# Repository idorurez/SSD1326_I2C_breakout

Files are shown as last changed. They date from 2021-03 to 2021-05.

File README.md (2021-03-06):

# SSD1326 256x32 I2C oled breakout

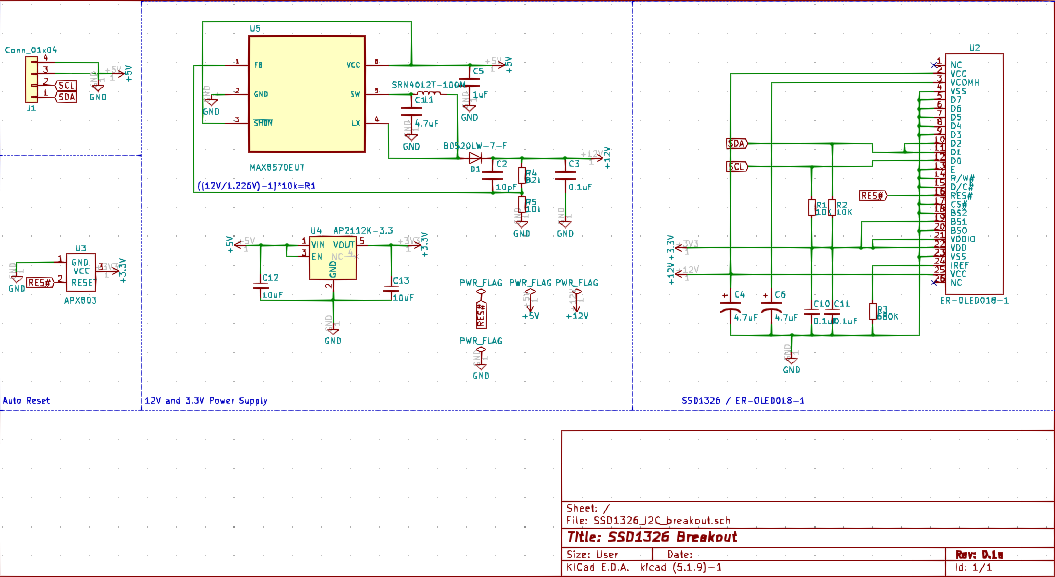
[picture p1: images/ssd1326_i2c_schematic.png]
schematic

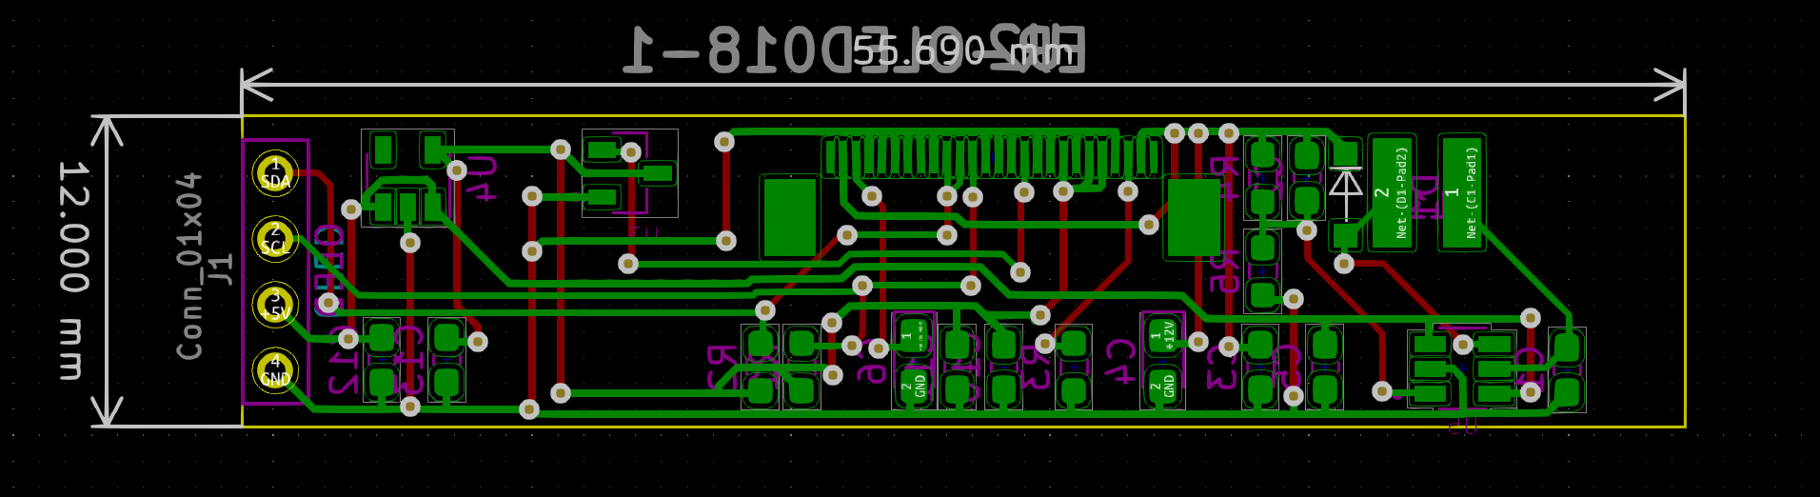
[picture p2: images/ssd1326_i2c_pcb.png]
pcb


## Features
* 5V+ in
* I2C
* Voltage regulator V3.3 out for logic
* Step up to 12V+ to power oled panel
* For use with ER-OLED01B-1 w/26 pin Ziff connector

## Notes
* `datasheet` folder includes datasheets for everything used here as well as ones I abandoned
* `onigaku` repo (not included in this repo) has all symbols and footprints are available

## Inspiration
* Adafruit schematics for latest SSD1306 breakout boards
* https://hackaday.io/project/173753-oled-breakout-board-with-dc-dc-step-up/details

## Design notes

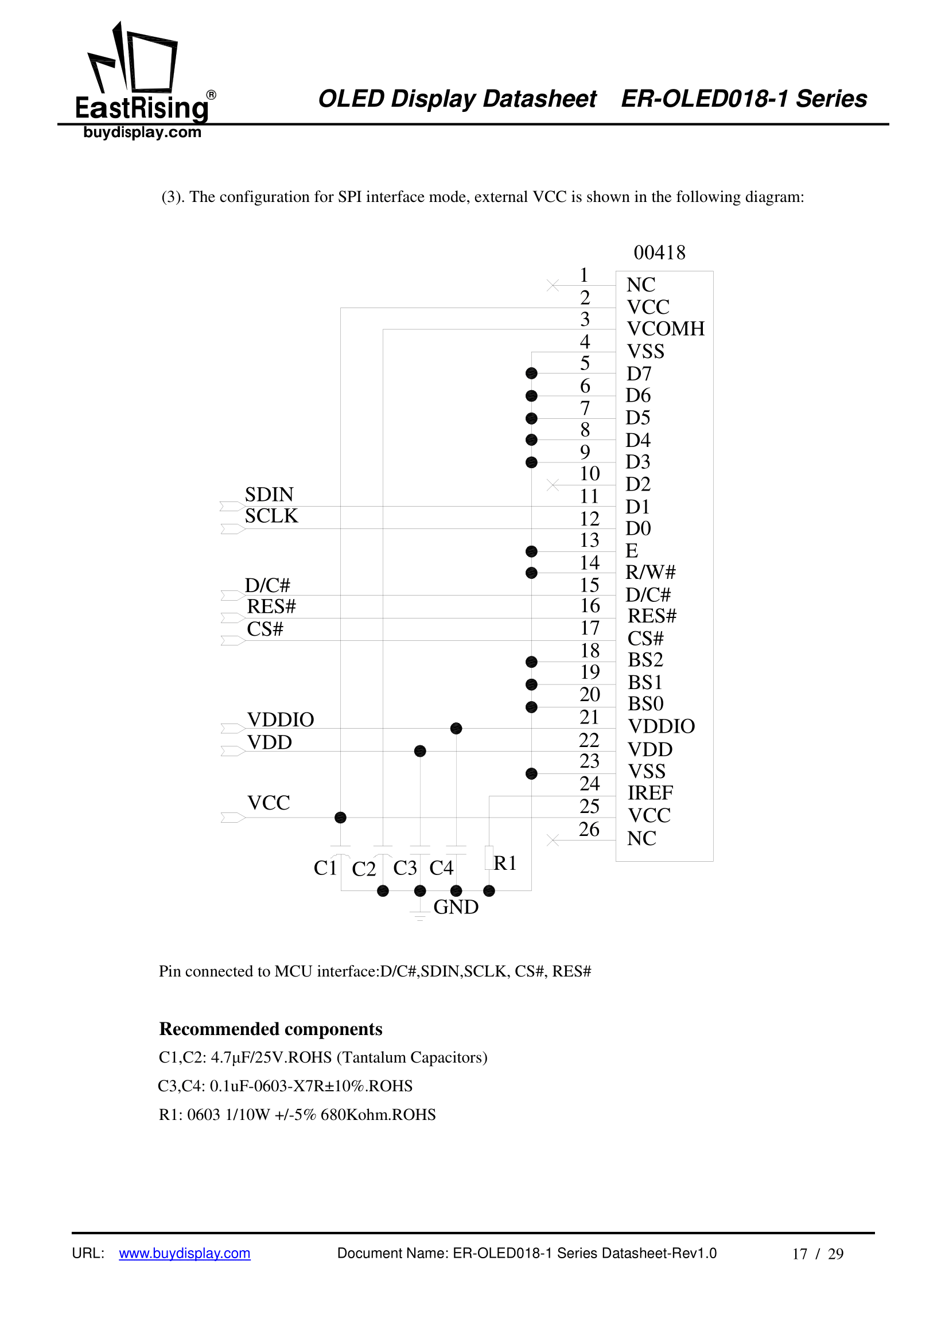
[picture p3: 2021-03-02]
datasheet/ER-OLED018-1_Series_Datasheet/ER-OLED018-1_Series_Datasheet-18.png

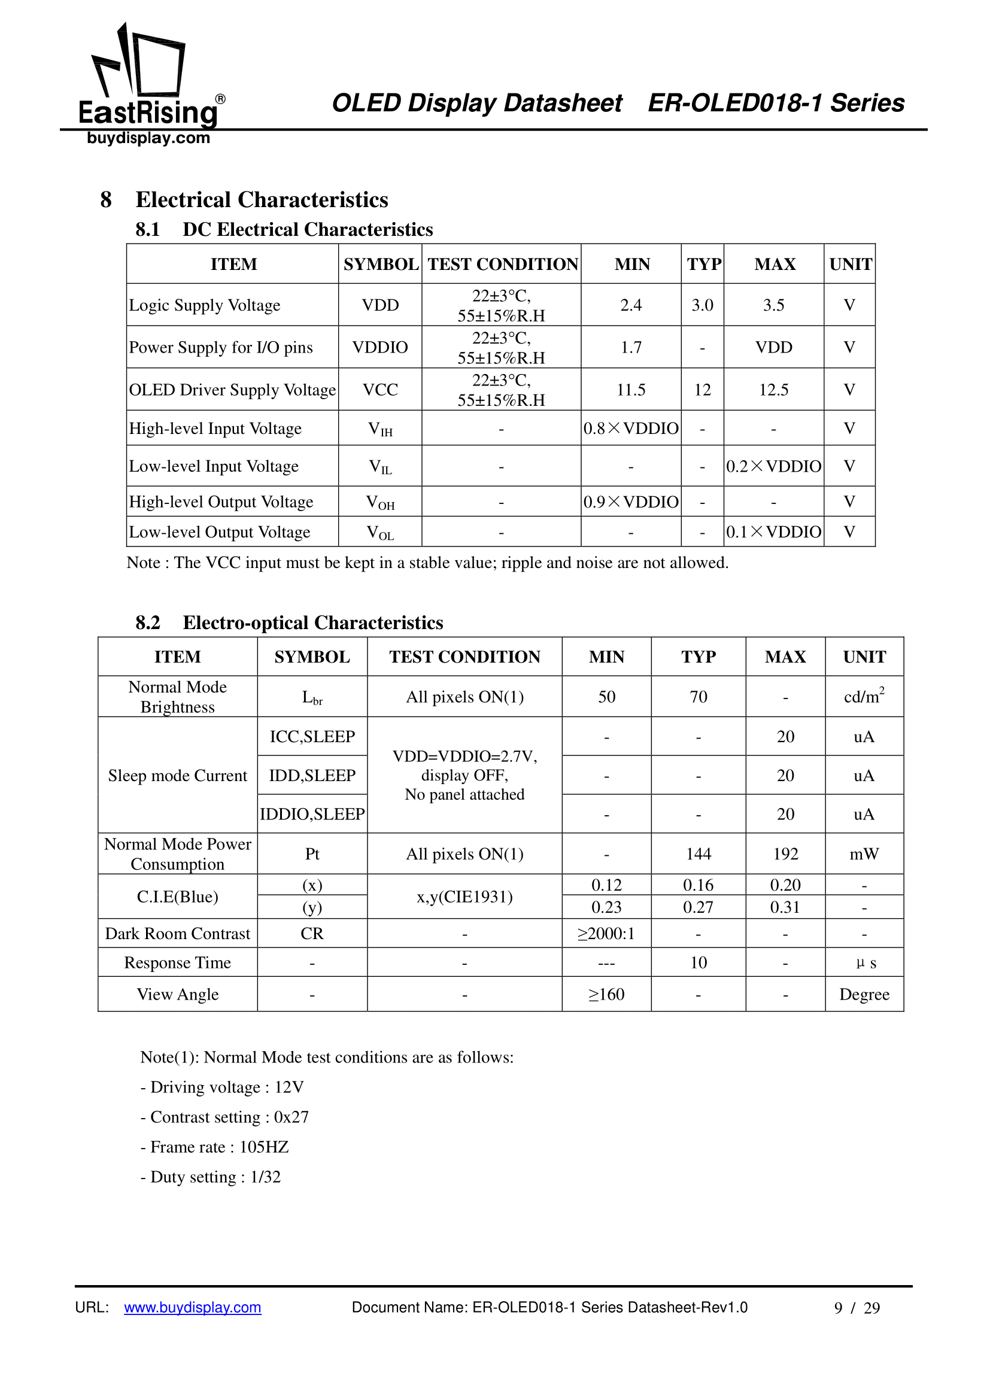
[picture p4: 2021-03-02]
datasheet/ER-OLED018-1_Series_Datasheet/ER-OLED018-1_Series_Datasheet-10.png

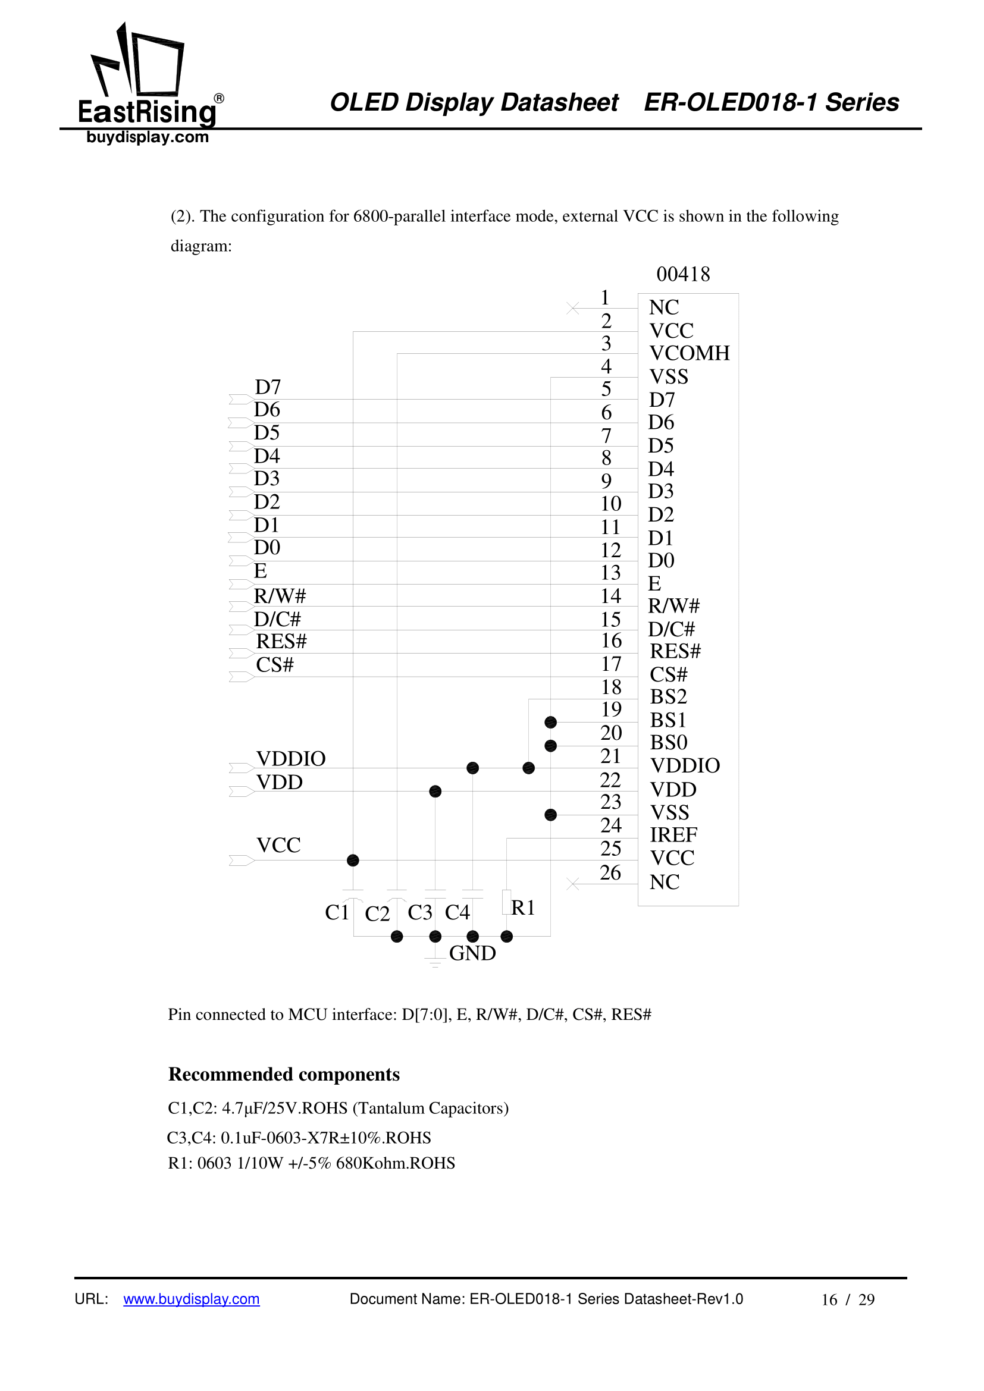
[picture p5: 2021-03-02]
datasheet/ER-OLED018-1_Series_Datasheet/ER-OLED018-1_Series_Datasheet-17.png

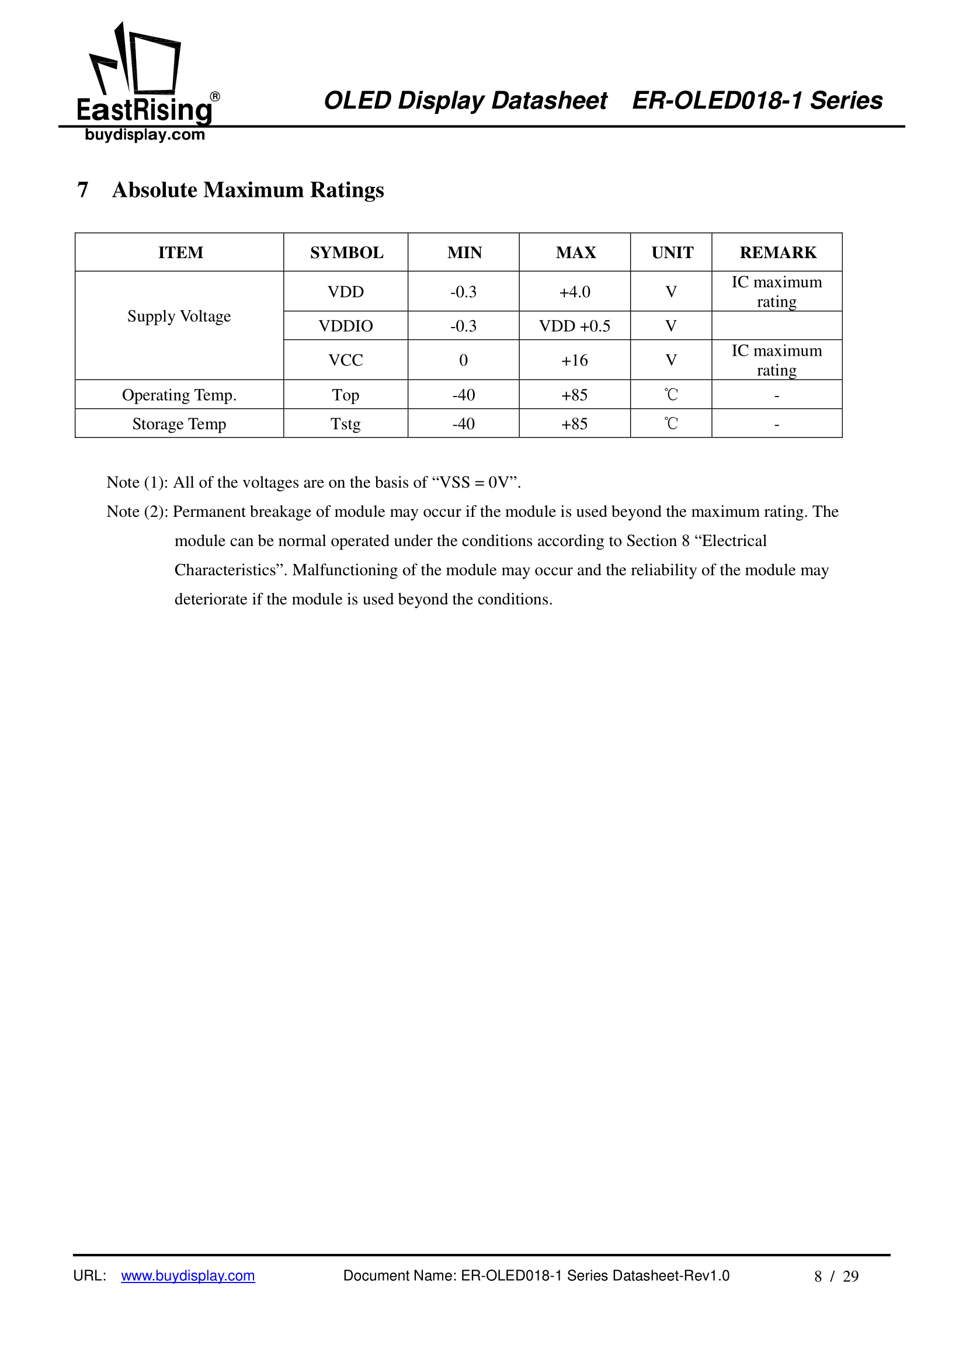
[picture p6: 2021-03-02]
datasheet/ER-OLED018-1_Series_Datasheet/ER-OLED018-1_Series_Datasheet-09.png

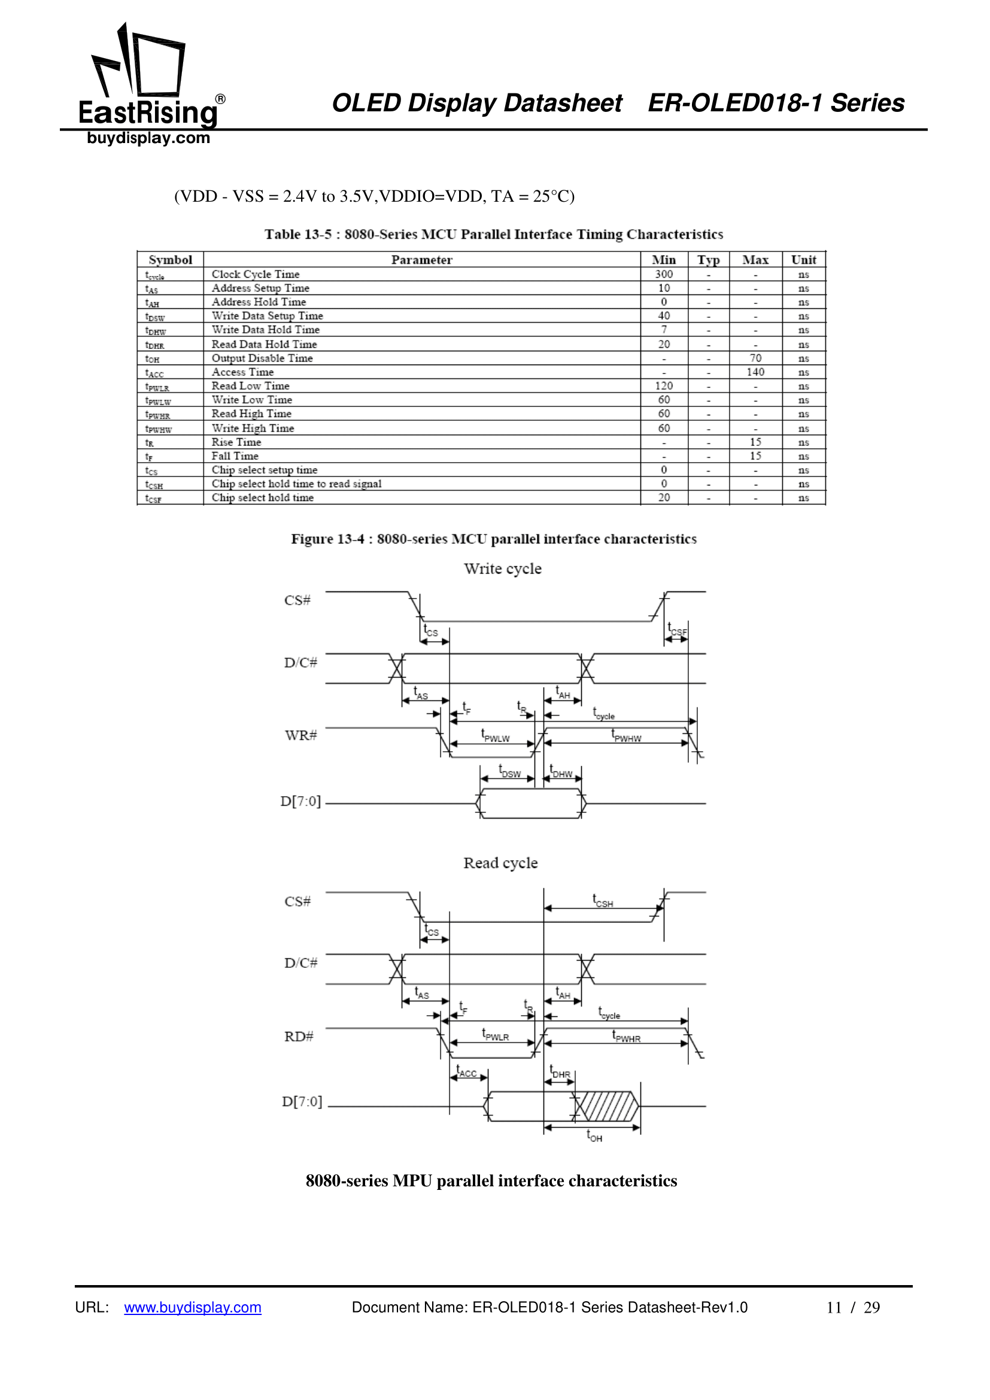
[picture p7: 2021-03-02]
datasheet/ER-OLED018-1_Series_Datasheet/ER-OLED018-1_Series_Datasheet-12.png

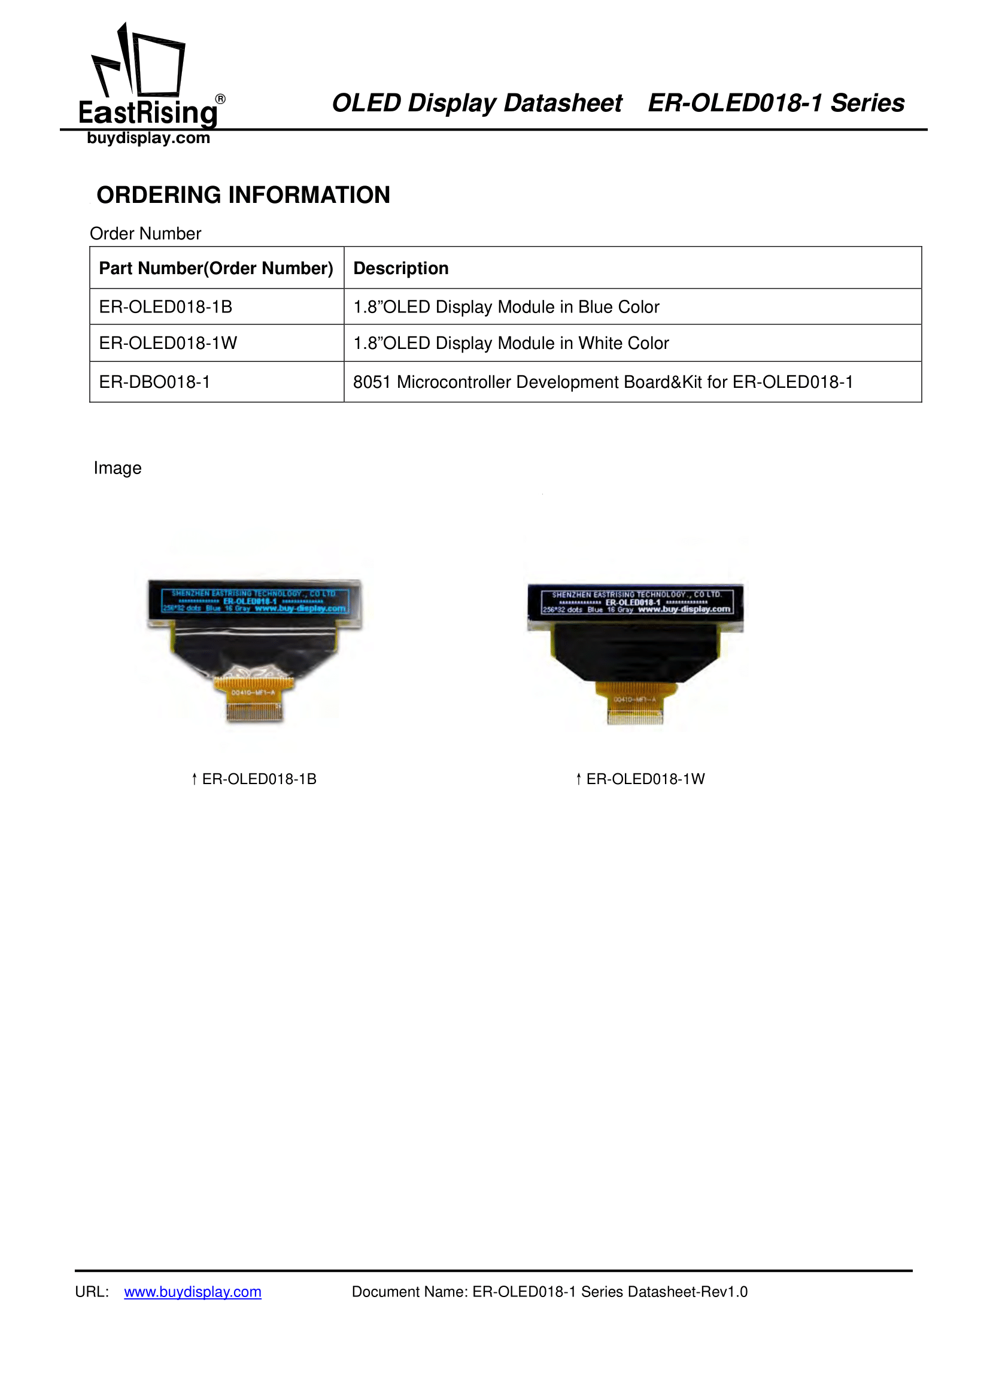
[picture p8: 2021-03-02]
datasheet/ER-OLED018-1_Series_Datasheet/ER-OLED018-1_Series_Datasheet-02.png

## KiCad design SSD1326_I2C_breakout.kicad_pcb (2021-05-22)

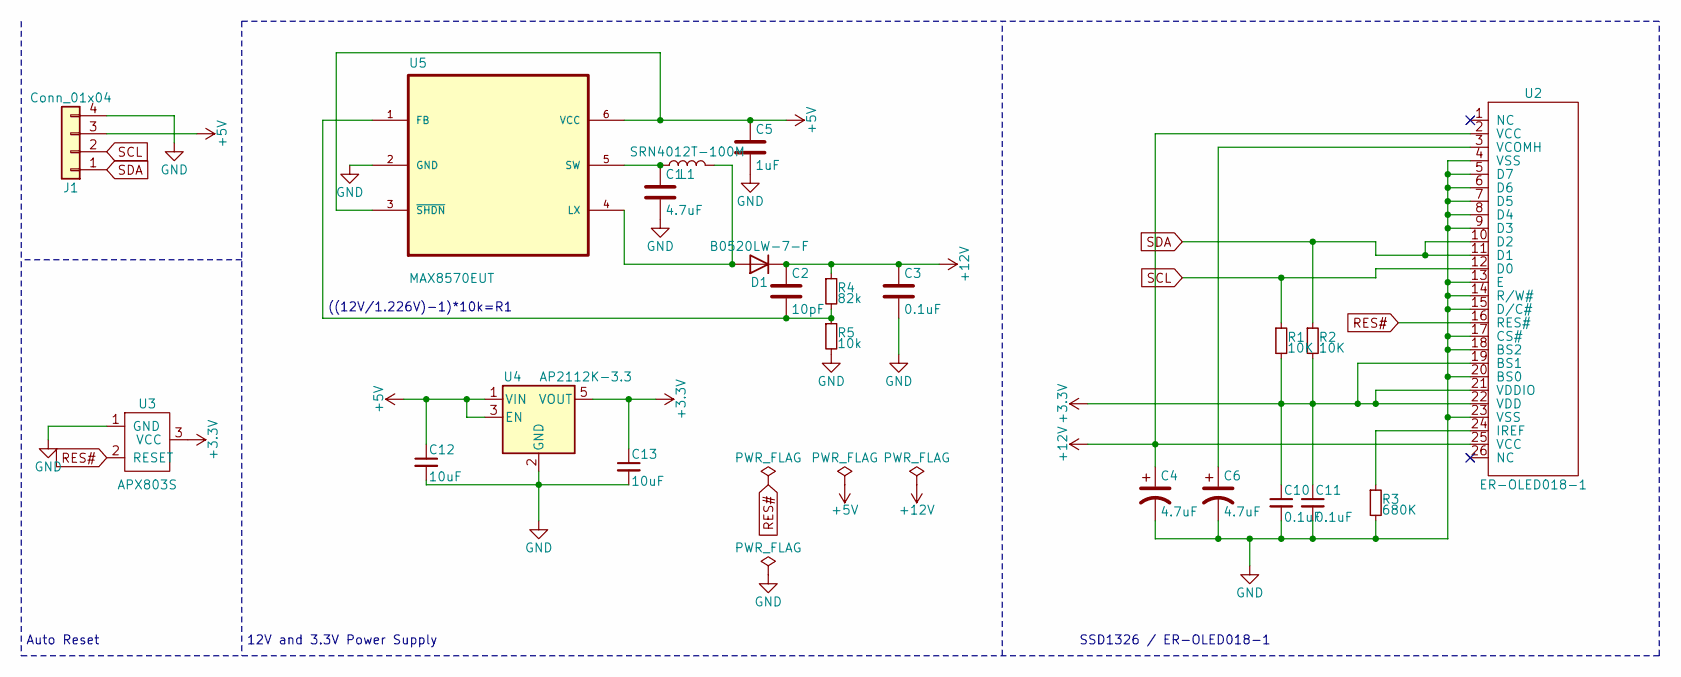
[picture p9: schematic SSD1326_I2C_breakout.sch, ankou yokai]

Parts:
C1: 4.7uF; C_0603_1608Metric_Pad1.08x0.95mm_HandSolder
C2: 10pF; C_0603_1608Metric_Pad1.08x0.95mm_HandSolder
C3, C10, C11: 0.1uF; C_0603_1608Metric_Pad1.08x0.95mm_HandSolder
C4, C6: 4.7uF; CP_EIA-2012-15_AVX-P_Pad1.30x1.05mm_HandSolder
C5: 1uF; C_0603_1608Metric_Pad1.08x0.95mm_HandSolder
C12, C13: 10uF; C_0603_1608Metric_Pad1.08x0.95mm_HandSolder
D1: ‎B0520LW-7-F‎; B0520LW
J1: Conn_01x04; OLED
L1: SRN4012T-100M
R1, R2: 10K; R_0603_1608Metric_Pad0.98x0.95mm_HandSolder
R3: 680K; R_0603_1608Metric_Pad0.98x0.95mm_HandSolder
R4: 82k; R_0603_1608Metric_Pad0.98x0.95mm_HandSolder
R5: 10k; R_0603_1608Metric_Pad0.98x0.95mm_HandSolder
U2: ER-OLED018-1; ER-CON26HT-1
U3: APX803S; APX803S-SA-SOT91P240X110-3N
U4: AP2112K-3.3; SOT-23-5
U5: MAX8570EUT; MAX8570EUT+SOT95P280X145-6N

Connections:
+3V3: C10.1, C11.1, C13.1, R1.2, R2.2, U2.19 (BS1), U2.21 (VDDIO), U2.22 (VDD), U3.3 (VCC), U4.5 (VOUT)
+5V: C5.1, C12.1, J1.3, U4.1 (VIN), U4.3 (EN), U5.3 (~SHDN), U5.6 (VCC); also elsewhere on the board
+12V: C2.1, C3.1, C4.1, D1.1 (K), R4.1, U2.2 (VCC), U2.25 (VCC)
GND: C1.2, C3.2, C4.2, C5.2, C6.2, C10.2, C11.2, C12.2, C13.2, J1.4, R3.2, R5.2, U2.4 (VSS), U2.5 (D7), U2.6 (D6), U2.7 (D5), U2.8 (D4), U2.9 (D3), U2.13 (E), U2.14 (R/W#), U2.15 (D/C#), U2.17 (CS#), U2.18 (BS2), U2.20 (BS0), U2.23 (VSS), U3.1 (GND), U4.2 (GND), U5.2 (GND); also elsewhere on the board
unnamed: C1.1, L1.1, U5.5 (SW)
unnamed: C2.2, R4.2, R5.1, U5.1 (FB)
unnamed: C6.1, U2.3 (VCOMH)
unnamed: D1.2 (A), L1.2, U5.4 (LX)
unnamed: R3.1, U2.24 (IREF)
RES#: U2.16 (RES#), U3.2 (RESET)
SCL: J1.2, R1.1, U2.12 (D0); also elsewhere on the board
SDA: J1.1, R2.1, U2.10 (D2), U2.11 (D1); also elsewhere on the board

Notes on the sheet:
12V and 3.3V Power Supply
Auto Reset
SSD1326 / ER-OLED018-1
((12V/1.226V)-1)*10k=R1

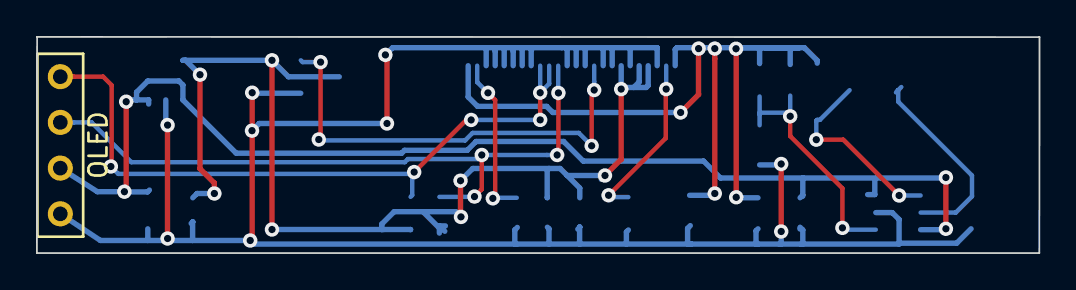
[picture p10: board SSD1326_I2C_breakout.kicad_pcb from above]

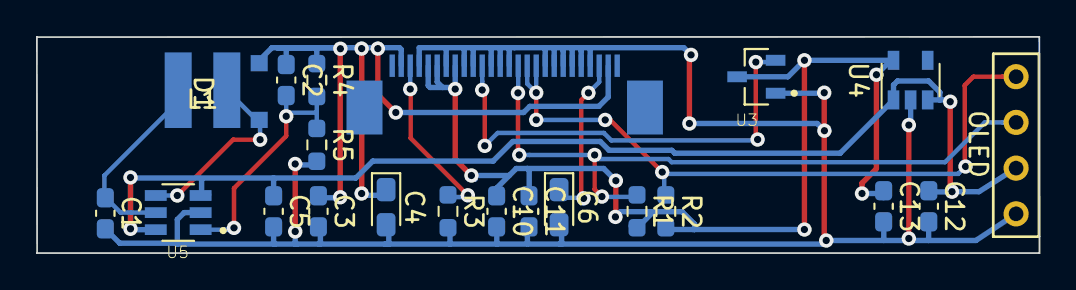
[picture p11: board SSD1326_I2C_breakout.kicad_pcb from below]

Board: 2 copper layers, 55.7 x 12.0 mm, 22 parts (21 on the bottom side), 12 nets.

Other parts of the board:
Jee: Conn_01x04; OLED

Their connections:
+5V: Jee.3; also elsewhere on the board
GND: Jee.4; also elsewhere on the board
SCL: Jee.2; also elsewhere on the board
SDA: Jee.1; also elsewhere on the board

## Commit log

2021-03-02 initial add
    [SD1326_I2C_breakout-B_Cu.gbr, SD1326_I2C_breakout-B_Mask.gbr, SD1326_I2C_breakout-B_Paste.gbr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]
2021-03-03 adding images and such
    [SSD1326_I2C_breakout.kicad_pcb, SSD1326_I2C_breakout.sch]
2021-03-04 swapped out max607 for a max8570 due to cost savings and obsoletion, using B0520LW schottky due to similar circumstances
    [SSD1326_I2C_breakout.kicad_pcb, SSD1326_I2C_breakout.sch]
2021-03-06 slimming down to 12mm
    [SD1326_I2C_breakout-F_SilkS.gbr, SSD1326_I2C_breakout-B_Cu.gbr, SSD1326_I2C_breakout-B_Mask.gbr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]
2021-05-22 moved some stuff over
    [SSD1326_I2C_breakout.kicad_pcb]
